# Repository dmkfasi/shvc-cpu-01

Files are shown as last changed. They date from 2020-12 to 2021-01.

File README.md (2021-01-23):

# SHVC-CPU-01

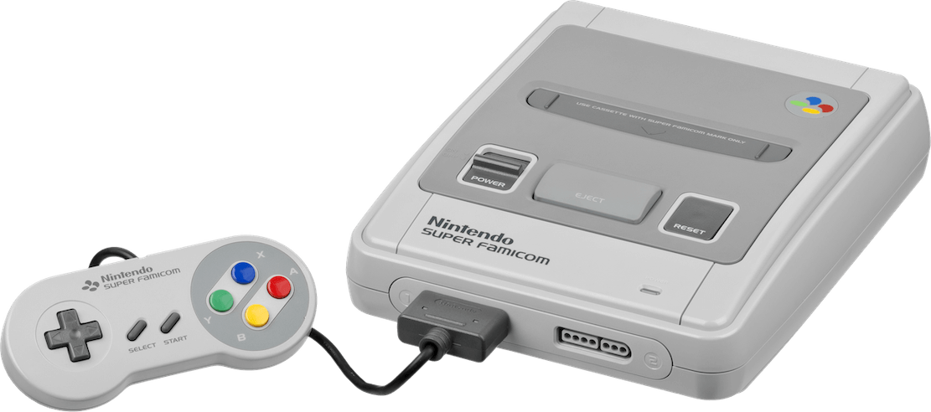
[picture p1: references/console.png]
Super Family Computer


This is a set of electronic schematics to preserve and recreate Super Family Computer also known as Super NES. Based on PDF files created by *Jonathon W. Donaldson* and *arzi84*.

Designed using [KiCAD EDA](https://kicad.org/).

### The primary goal of this project is to verify publicly available schematics for SNS-CPU-GPM-01 (and other revisions) by implementing these in hardware;

The secondary goals of this project are as follows:
1. Recreate the PCB using mixture of original and modern components to fit smaller size case, possibly for portable variant;
1. Get rid of unused components (such as RF modulator, extension ports, etc) or replace them with custom sub-boards or CPLD/FPGA components;
1. Fiddle around with analogue RGB output from S-PPU2 and sniff data bus for possible digital to digital (or digital to VGA) video output;
1. Design a breakout board for video subsystem (S-PPU1, S-PPU2, SRAM) for purpose of BSNES authors to connect such board to a PC and figure out more details for more accurate emulation:
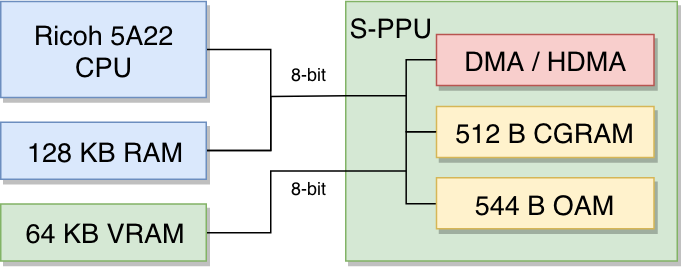
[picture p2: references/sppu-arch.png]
S-PPU architecture
 (drawings by Rodrigo Copetti)

Present limitations:
* ~~S-WRAM chip package is unknown, seems like a custom one, need to measure actual chip and footprint~~ ~~Done, but with impresice tool~~ Verified with digital calipers;
* ~~F411 CIC chip footprint needs verification~~ ~~Done, verified but with imprecise tool~~ Confirmed, see notes below;
* ~~S-SMP QFP-64 14x20mm needs custom designed footprint~~ ~~Done, needs verification against real chip~~ Confirmed QFP-64 14x20mm;
* My reference board is SNS-CPU-RGB-01;

---
Notes and references:

* S-CPU, S-PPU1, S-PPU2 and S-DSP seem to be PQFP-100 14x20mm
* SRAM, PSRAM are standard SOP-28, footprint redesigned
* F411 CIC seems to be SSOP-18 6.0x7.6mm, custom footprint designed
* S-SMP assigned PQFP-64 1.0mm pitch footprint
* S-WRAM assigned SOP-64 0.8mm pitch footprint, 26.6x11.0mm body

* Pin pitch = 2.5mm (not 2.54mm)
* PCB thickness = 1.2mm
* SNS-CPU-RGB-01 PCB thickness = 1.6mm

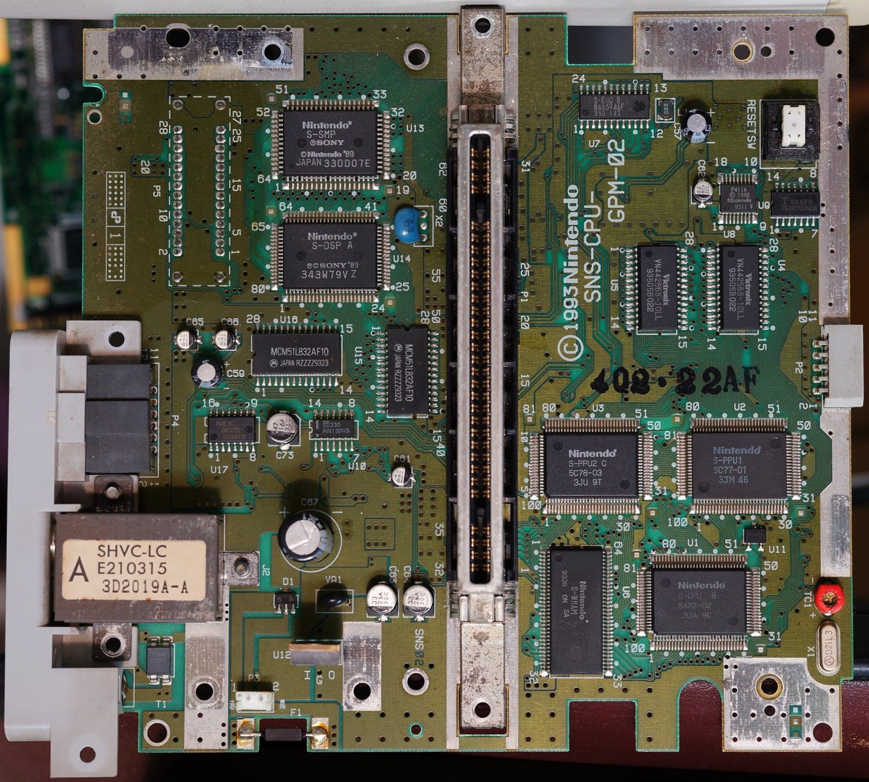
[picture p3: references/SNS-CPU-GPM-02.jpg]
PCB


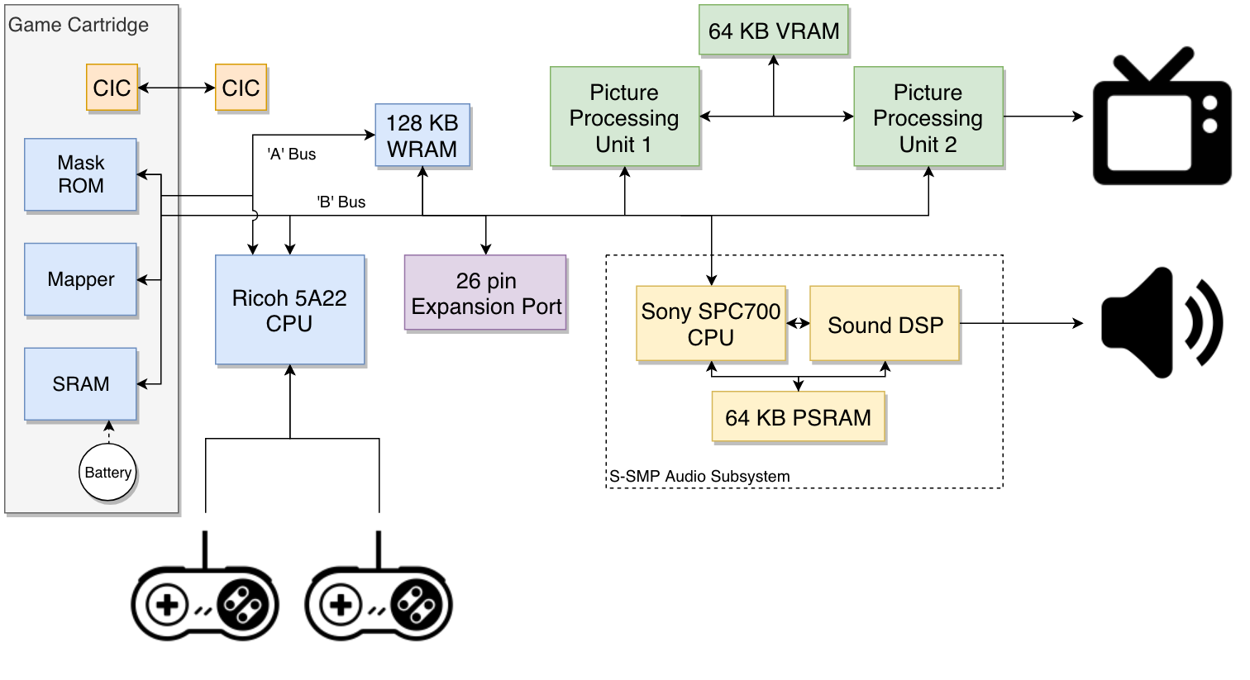
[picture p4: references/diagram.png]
Block diagram
 (drawings by Rodrigo Copetti)

---

# Work in progress
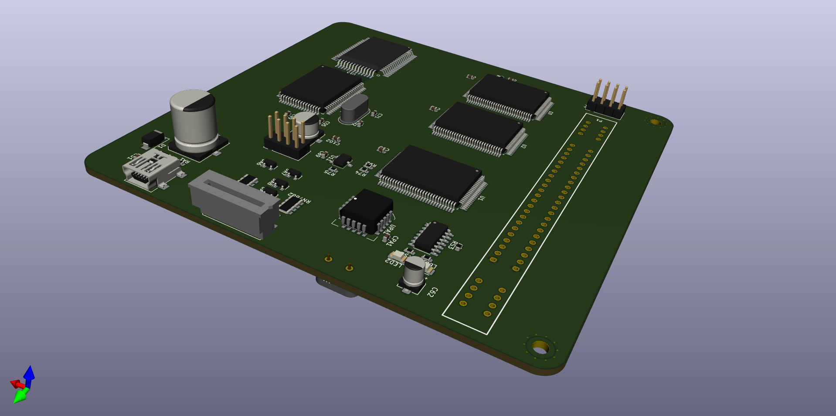
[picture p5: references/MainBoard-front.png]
Front face

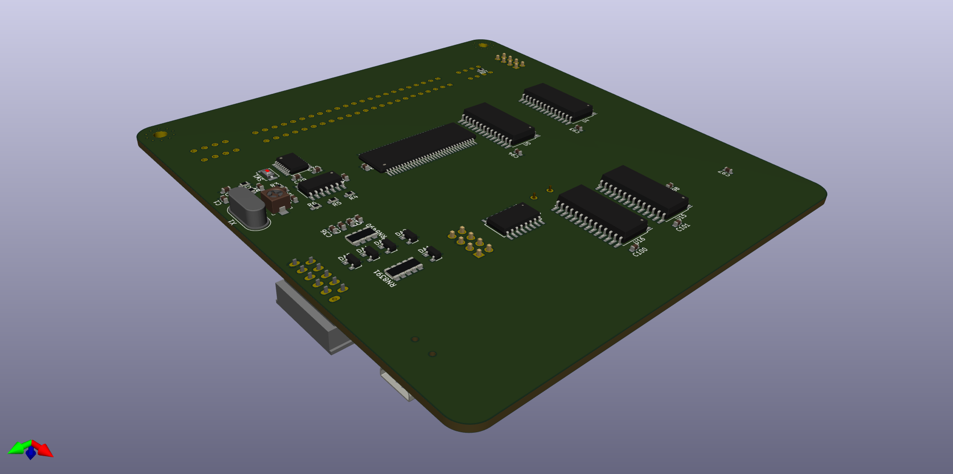
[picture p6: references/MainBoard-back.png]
Back face


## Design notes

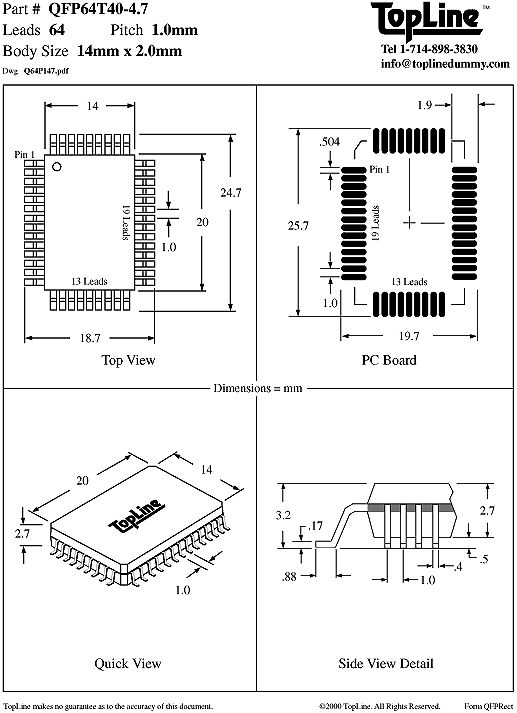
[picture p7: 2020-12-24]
references/QFP64T40-4.7.gif

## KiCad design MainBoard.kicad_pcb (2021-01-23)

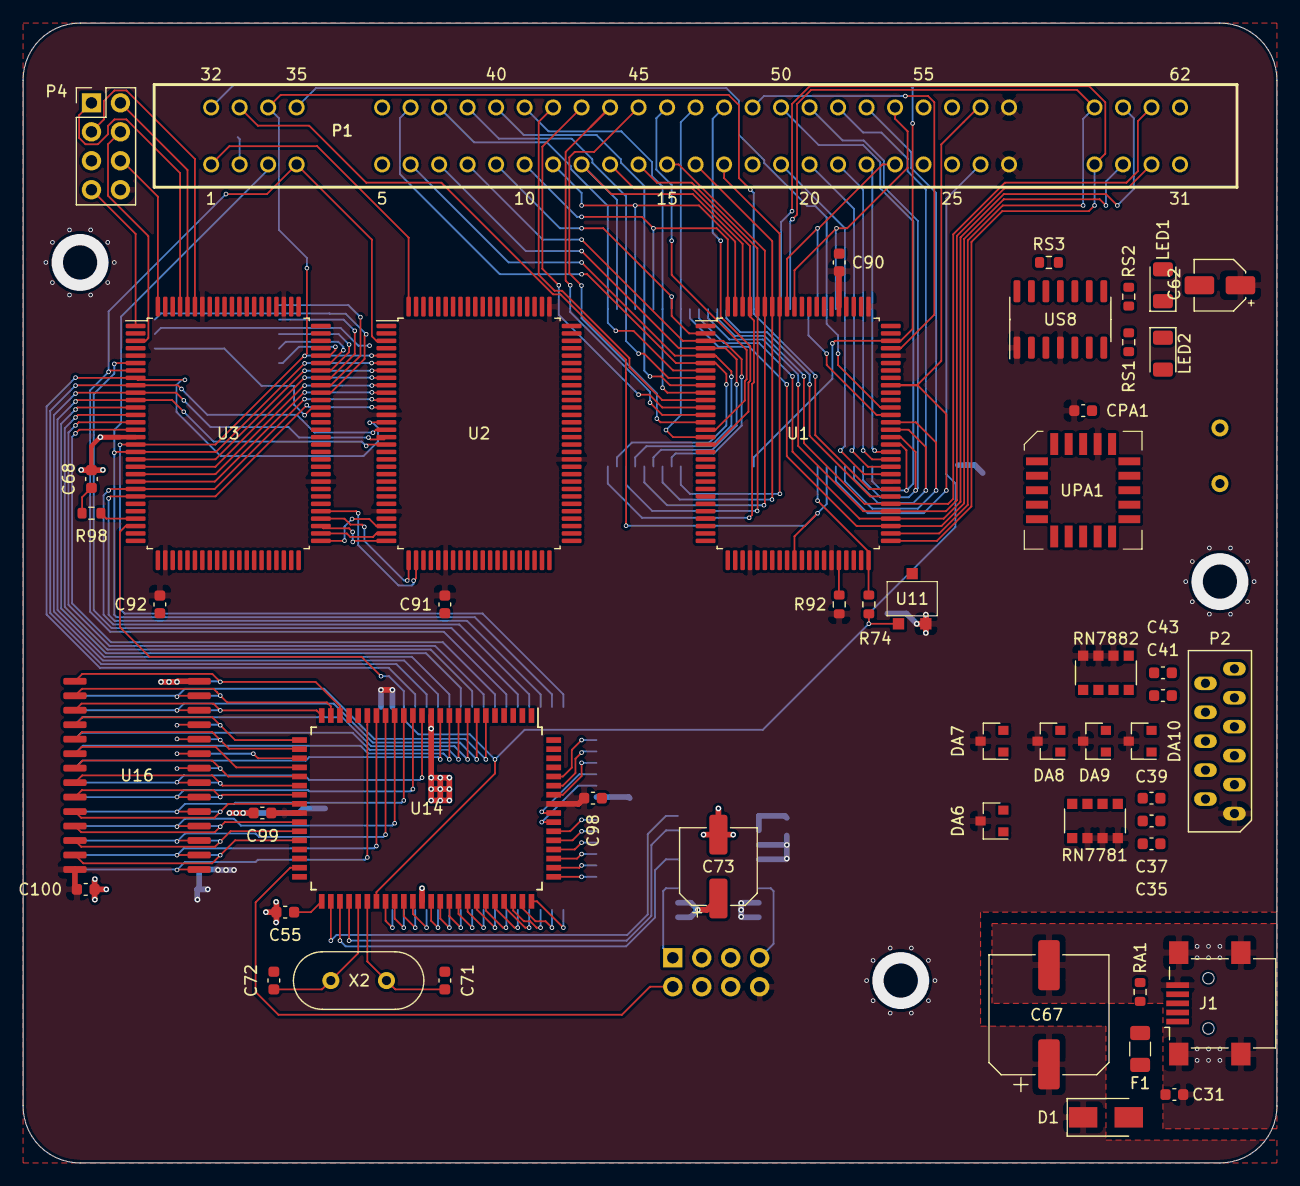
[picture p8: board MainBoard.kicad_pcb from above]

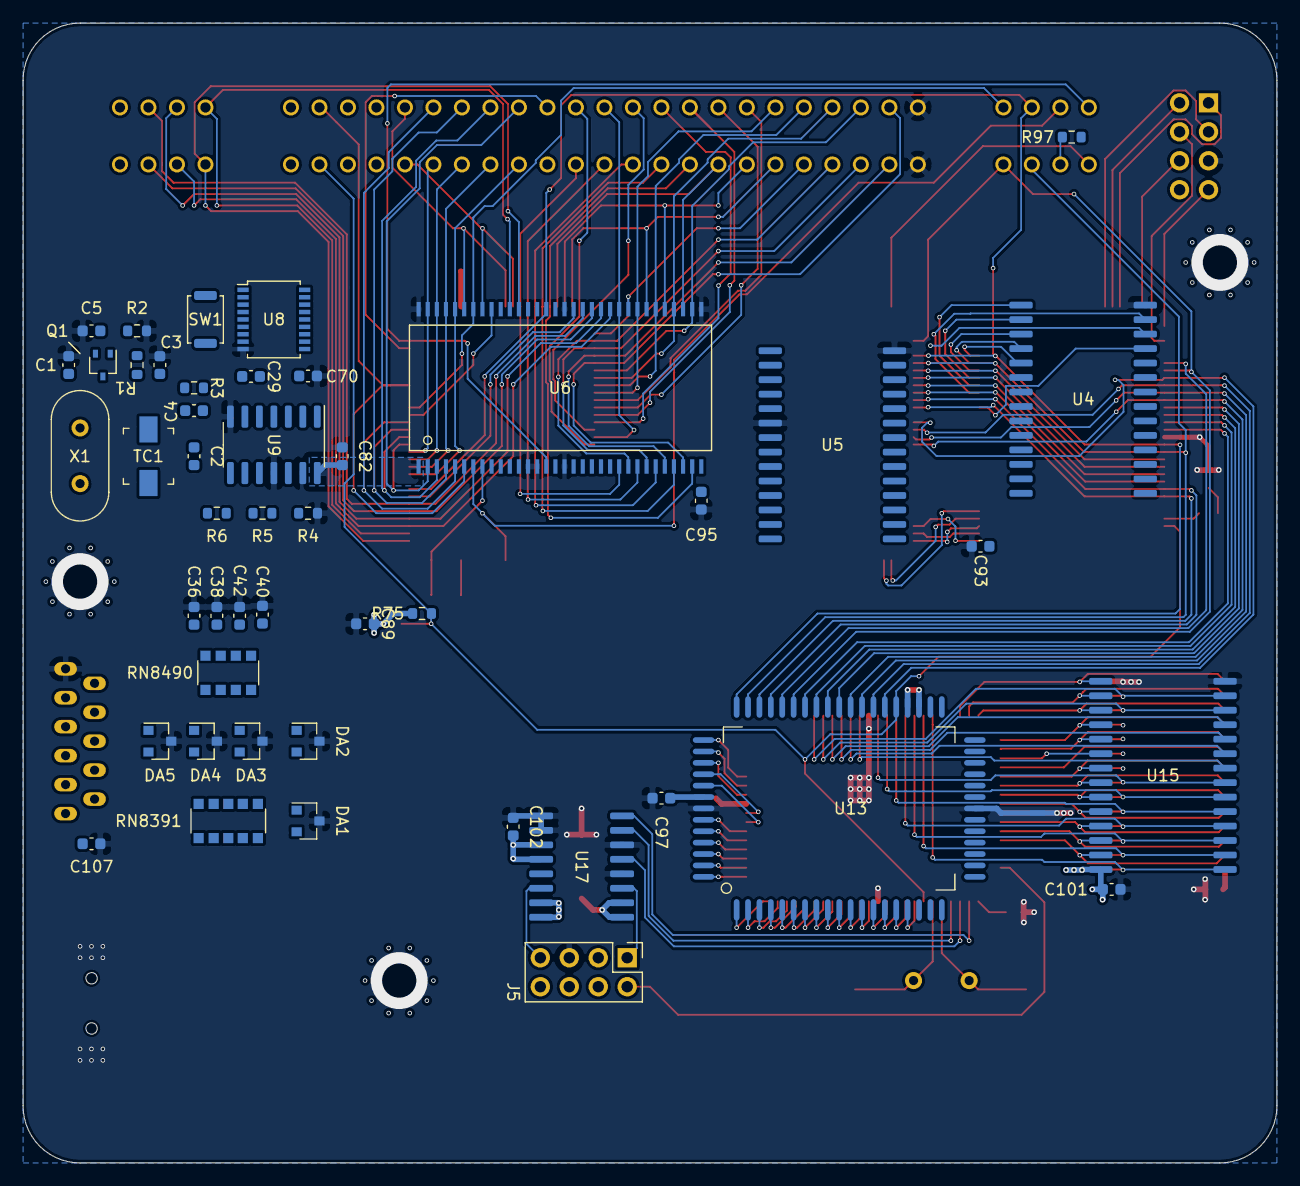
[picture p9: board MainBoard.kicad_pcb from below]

Board: 4 copper layers, 110.0 x 100.0 mm, 98 parts (47 on the bottom side), 236 nets.

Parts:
C1: 47pF; C_0603_1608Metric
C2: 15pF; C_0603_1608Metric
C3: 10pF; C_0603_1608Metric
C4: 100pF; C_0603_1608Metric
C5, C107: 0.01uF; C_0603_1608Metric
C29, C82, C90, C91, C92, C93, C95, C97, C98, C99, C100, C101, C102: 0.1uF; C_0603_1608Metric
C31: 0.01uF 50V; C_0603_1608Metric
C35, C36, C37, C38, C39, C40, C41, C42, C43: 330pF; C_0603_1608Metric
C55: (0); C_0603_1608Metric
C62: 2.2uF; CP_Elec_4x5.4
C67: 1000uF 25V; CP_Elec_10x12.6
C68: 56pF; C_0603_1608Metric
C70: 82pF; C_0603_1608Metric
C71, C72: 3pF; C_0603_1608Metric
C73: 47uF (10V); CP_Elec_6.3x5.4
C89: 100nF; C_0603_1608Metric
CPA1: 100nF; C_0603_1608Metric
D1: PB1100; D_SMA
DA1, DA2, DA3, DA4, DA5: BAT54A; SOT-23
DA6, DA7, DA8, DA9, DA10: BAT54C; SOT-23
F1: Polyfuse; Fuse_1206_3216Metric
J1: USB B Mini; USB_Mini-B_Lumberg_2486_01_Horizontal
J5: Audio Out Port; PinHeader_2x04_P2.54mm_Vertical
LED1: GREEN; LED_1206_3216Metric
LED2: RED; LED_1206_3216Metric
P1: CARTRIDGE_SLOT; SNES_RETRODE_SLOT
P2: FRONT_PANEL_CONNECTOR; SNES_JOYPAD_PORT_ZIP-11
P4: Multi AV Out; PinHeader_2x04_P2.54mm_Vertical
Q1: 2SC4699; SOT-323_SC-70
R1: 56K; R_0603_1608Metric
R2, R4: 210; R_0603_1608Metric
R3: 1.2K; R_0603_1608Metric
R5: 39; R_0603_1608Metric
R6, R75: 100K; R_0603_1608Metric
R74: 1K; R_0603_1608Metric
R92, R97: 10K; R_0603_1608Metric
R98: 100; R_0603_1608Metric
RA1: 100; R_0603_1608Metric
RN7781, RN7882: 10K; R_Array_Convex_4x1206
RN8391: 100; R_Array_Convex_5x1206
RN8490: 100; R_Array_Convex_4x1206
RS1, RS2: 180; R_0603_1608Metric
RS3: 10K; R_0603_1608Metric
SW1: RESET; SW_Push_SPST_NO_Alps_SKRK
TC1: 20pF; C_Trimmer_Murata_TZB4-A
U1: S-CPU; PQFP-100_14x20mm_P0.65mm
U2: S-PPU1; PQFP-100_14x20mm_P0.65mm
U3: S-PPU2; PQFP-100_14x20mm_P0.65mm
U4, U5: SRAM; SOP-28-330mil_P1.27mm
U6: S-WRAM; SOP-64_10.9x26.5mm_P0.8mm
U8: CIC; SSOP-18_4.4x6.5mm_P0.65mm
U9: HCU04; SOIC-14_3.9x8.7mm_P1.27mm
U11: PST529D; MMP-3A
U13: S-SMP; PQFP-64_14x20mm_P1.0mm
U14: S-DSP; PQFP-80_14x20mm_P0.8mm
U15, U16: PSRAM; SOP-28-330mil_P1.27mm
U17: UPD6376; SOP-16-300mil_P1.27mm
UPA1: 16V8; PLCC-20
US8: SuperCIC; SOIC-14_3.9x8.7mm_P1.27mm
X1: 21.47727 MHz; Crystal_HC49-4H_Vertical
X2: 24.576MHz; Crystal_HC49-4H_Vertical

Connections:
/3.58M: P4.4, U3.3
/4016.D0: DA3.2, DA8.1, RN7781.3, RN8391.8, U1.32
/4016.D1: DA3.1, DA8.2, RN7882.1, RN8490.7, U1.33
/4017.D0: DA4.2, DA9.1, RN7781.2, RN8391.9, U1.27
/4017.D1: DA4.1, DA9.2, RN7882.2, RN8490.6, U1.28
/$214F_PATCH: UPA1.13, US8.3
/AUDIO_LOUT: J5.1, U17.11
/AUDIO_ROUT: J5.7, U17.6
/CA0: P1.17, U1.93, U6.23
/CA1: P1.16, U1.94, U6.25
/CA2: P1.15, U1.95, U6.27
/CA3: P1.14, U1.96, U6.29
/CA4: P1.13, U1.97, U6.31
/CA5: P1.12, U1.98, U6.35
/CA6: P1.11, U1.99, U6.37
/CA7: P1.10, U1.100, U6.39
/CA8: P1.9, U1.2, U6.41
/CA9: P1.8, U1.3, U6.24
/CA10: P1.7, U1.4, U6.26
/CA11: P1.6, U1.5, U6.28
/CA12: P1.37, U1.6, U6.30
/CA13: P1.38, U1.7, U6.34
/CA14: P1.39, U1.8, U6.36
/CA15: P1.40, U1.9, U6.38
/CA16: P1.41, U1.10, U6.40
/CA17: P1.42, U1.11
/CA18: P1.43, U1.12
/CA19: P1.44, U1.13
/CA20: P1.45, U1.14
/CA21: P1.46, U1.15
/CA22: P1.47, U1.16, U6.42
/CA23: P1.48, U1.17
/CART_SOUND-L: J5.3, P1.31
/CART_SOUND-R: J5.6, P1.62
/CHR0: U2.85, U3.46
/CHR1: U2.84, U3.47
/CHR2: U2.83, U3.48
/CHR3: U2.82, U3.49
/CIC0: P1.24, U8.2, US8.9
/CIC1: P1.55, U8.1, US8.10
/CIC2: P1.25, U8.11, US8.8
/CIC3: C70.1, P1.56, U9.2
/CIC_CL1: U8.7, U9.4, US8.2
/CIC_RESET: C29.2, RS3.2, SW1.1, U8.8, US8.13
/COLOR0: U2.90, U3.41
/COLOR1: U2.89, U3.42
/COLOR2: U2.88, U3.43
/D0: P1.19, U1.60, U2.21, U3.15, U6.60, U13.45
/D1: P1.20, U1.61, U2.20, U3.14, U6.61, U13.44
/D2: P1.21, U1.62, U2.19, U3.13, U6.62, U13.43
/D3: P1.22, U1.63, U2.18, U3.12, U6.63, U13.42
/D4: P1.50, U1.64, U2.17, U3.11, U6.2, U13.41, UPA1.16, UPA1.17, UPA1.18, UPA1.19
/D5: P1.51, U1.65, U2.16, U3.10, U6.3, U13.40
/D6: P1.52, U1.66, U2.15, U3.9, U6.4, U13.39
/D7: P1.53, U1.67, U2.14, U3.8, U6.5, U13.38
/FIELD: U2.95, U3.36
/HBLANK: U1.43, U3.25
/JPCLK1: DA2.2, DA7.1, RN8391.7, U1.35
/JPCLK2: DA2.1, DA7.2, RN8490.8, U1.36
/JPIO6: DA5.2, DA10.1, RN7781.1, RN8391.10, U1.25
/JPIO7: DA5.1, DA10.2, RN7882.3, RN8490.5, U1.26, U3.29
/JPSTR: DA1.1, DA6.2, RN8391.6, U1.37
/MA0: U14.9, U15.10, U16.10
/MA1: U14.10, U15.9, U16.9
/MA2: U14.11, U15.8, U16.8
/MA3: U14.13, U15.7, U16.7
/MA4: U14.14, U15.6, U16.6
/MA5: U14.15, U15.5, U16.5
/MA6: U14.16, U15.4, U16.4
/MA7: U14.17, U15.3, U16.3
/MA8: U14.34, U15.25, U16.25
/MA9: U14.32, U15.24, U16.24
/MA10: U14.29, U15.21, U16.21
/MA11: U14.31, U15.23, U16.23
/MA12: U14.18, U15.2, U16.2
/MA13: U14.35, U15.26, U16.26
/MA14: U14.19, U15.1, U16.1
/MD0: U14.8, U15.11, U16.11
/MD1: U14.7, U15.12, U16.12
/MD2: U14.6, U15.13, U16.13
/MD3: U14.22, U15.15, U16.15
/MD4: U14.23, U15.16, U16.16
/MD5: U14.24, U15.17, U16.17
/MD6: U14.25, U15.18, U16.18
/MD7: U14.26, U15.19, U16.19
/PA0: P1.28, U1.51, U2.12, U3.24, U6.53, U13.49, UPA1.1
/PA1: P1.59, U1.52, U2.11, U3.23, U6.54, U13.48, UPA1.5
/PA2: P1.29, U1.53, U2.10, U3.22, U6.43, UPA1.2
/PA3: P1.60, U1.54, U2.9, U3.21, U6.44, UPA1.6
/PA4: P1.30, U1.55, U2.8, U3.20, U6.45, UPA1.3
/PA5: P1.61, U1.56, U2.7, U3.19, U6.46, UPA1.7
/PA6: P1.3, U1.57, U2.6, U3.18, U6.47, U13.50, UPA1.4
/PA7: P1.34, U1.58, U2.5, U3.17, U6.50, U13.51, UPA1.8
/PRIO0: U2.87, U3.44
/PRIO1: U2.86, U3.45
/Post_Amplifier: DA1.2, DA6.1
/REFRESH: P1.33, U1.40, U6.7
/SCLK: C55.1, U9.1, U9.3, U14.41
/SYSCK: P1.57, U1.72, U6.6
/VA14: U2.47, U4.1, U5.1
/VAA0: U2.76, U5.10
/VAA1: U2.75, U5.9
/VAA2: U2.74, U5.8
/VAA3: U2.73, U5.7
/VAA4: U2.72, U5.6
/VAA5: U2.71, U5.5
/VAA6: U2.70, U5.4
/VAA7: U2.69, U5.3
/VAA8: U2.68, U5.25
/VAA9: U2.67, U5.24
/VAA10: U2.66, U5.21
/VAA11: U2.65, U5.23
/VAA12: U2.64, U5.2
/VAA13: U2.63, U5.26
/VAB0: U2.61, U4.10
/VAB1: U2.60, U4.9
/VAB2: U2.59, U4.8
/VAB3: U2.58, U4.7
/VAB4: U2.57, U4.6
/VAB5: U2.56, U4.5
/VAB6: U2.55, U4.4
/VAB7: U2.54, U4.3
/VAB8: U2.53, U4.25
/VAB9: U2.52, U4.24
/VAB10: U2.51, U4.21
/VAB11: U2.50, U4.23
/VAB12: U2.49, U4.2
/VAB13: U2.48, U4.26
/VBLANK: U1.44, U3.26
/VDA0: U2.37, U3.60, U5.11
/VDA1: U2.38, U3.61, U5.12
/VDA2: U2.39, U3.62, U5.13
/VDA3: U2.40, U3.63, U5.15
/VDA4: U2.41, U3.64, U5.16
/VDA5: U2.42, U3.65, U5.17
/VDA6: U2.43, U3.66, U5.18
/VDA7: U2.44, U3.67, U5.19
/VDB0: U2.28, U3.51, U3.69, U4.11
/VDB1: U2.29, U3.52, U3.70, U4.12
/VDB2: U2.30, U3.53, U3.71, U4.13
/VDB3: U2.31, U3.54, U3.72, U4.15
/VDB4: U2.32, U3.55, U3.73, U4.16
/VDB5: U2.33, U3.56, U3.74, U4.17
/VDB6: U2.34, U3.57, U3.75, U4.18
/VDB7: U2.35, U3.58, U3.76, U4.19
/VIDEO_B: P4.3, U3.95
/VIDEO_G: P4.2, U3.96
/VIDEO_R: P4.1, U3.97
/XIN: P1.1, R4.2, R5.1, U1.48, U2.100, U3.31
/~5MIN: U2.93, U2.94, U2.97, U3.37, U3.38, U3.50
/~CE0: U14.28, U16.20
/~CE1: U14.27, U15.20
/~CPURD: P1.23, U1.92, U6.57
/~CPUWR: P1.54, U1.91, U6.59
/~HCLD: U2.92, U3.39
/~IRQ: P1.18, R92.2, U1.46
/~MUTE: J5.2, U14.39
/~OE: U14.30, U15.22, U16.22
/~PARD: P1.4, U1.68, U2.3, U3.7, U6.56, U13.46, UPA1.9
/~PAWR: P1.35, U1.69, U2.4, U3.6, U6.58, U13.47
/~RAMSEL: P1.32, U1.78, U6.15
/~RESET: U3.34, U8.10, US8.11
/~RESOUT0: U2.98, U3.33
/~RESOUT1: P1.26, R74.1, R74.2, R75.1, U1.50, U3.28, U6.8, U11.2, U13.37, U14.47
/~ROMSEL: P1.49, U1.77
/~VAWR: U2.78, U5.27
/~VBWR: U2.79, U4.27
/~VCLD: U2.91, U3.40
/~VIDEO_BURST: P4.6, U3.100
/~VIDEO_CSYNC: P4.7, U3.1
/~VRD: U2.80, U4.22, U5.22
/~WE: U14.36, U15.27, U16.27
GND: C1.2, C3.2, C5.2, C31.1, C35.2, C36.2, C37.2, C38.2, C39.2, C40.1, C41.2, C42.2, C43.2, C55.2, C67.2, C68.2, C70.2, C71.1, C72.1, C73.2, C82.2, C89.2, C90.1, C91.1, C92.1, C93.1, C95.1, C97.2, C98.1, C99.2, C100.1, C101.1, C102.1, C107.2, CPA1.2, DA1.3, DA2.3, DA3.3, DA4.3, DA5.3, J1.5, J1.6, J5.5, LED1.1, LED2.1, P1.5, P1.36, P2.11, P4.5, R2.1, R4.1, RS3.1, U1.18, U1.29, U1.30, U1.31, U1.41, U1.42, U1.47, U1.49, U1.73, U1.74, U1.75, U1.79, U1.90, U2.1, U2.2, U2.22, U2.23, U2.24, U2.25, U2.27, U2.45, U2.77, U2.96, U2.99, U3.16, U3.30, U3.35, U3.68, U3.90, U3.91, U3.92, U3.93, U3.98, U3.99, U4.14, U4.20, U5.14, U5.20, U6.13, U6.14, U6.17, U6.33, U6.48, U6.64, U8.9, U9.7, U9.11, U9.13, U11.3, U13.26, U13.58, U14.12, U14.37, U14.38, U14.52, U15.14, U16.14, U17.1, U17.2, U17.12, U17.14, UPA1.10, US8.7, US8.12, US8.14
unnamed: C1.1, X1.2
unnamed: C2.1, TC1.1, X1.1
unnamed: C2.2, C3.1, C4.2, Q1.3, R1.2, R3.1, TC1.2
unnamed: C4.1, R6.2, U9.9
unnamed: C5.1, Q1.2, R2.2
unnamed: C31.2, D1.2, F1.2
unnamed: C35.1, P2.2, RN8391.1
unnamed: C36.1, P2.3, RN8490.4
unnamed: C37.1, P2.4, RN8391.2
unnamed: C38.1, P2.5, RN8490.3
unnamed: C39.1, P2.6, RN8391.3
unnamed: C40.2, P2.7, RN8490.2
unnamed: C41.1, P2.8, RN8391.4
unnamed: C42.1, P2.9, RN8490.1
unnamed: C43.1, P2.10, RN8391.5
unnamed: C62.2, U8.3
unnamed: C68.1, R98.2
unnamed: C71.2, U14.46, X2.2
unnamed: C72.2, U14.45, X2.1
unnamed: C73.1, U17.9, U17.10
unnamed: F1.1, J1.1
unnamed: J1.2, RA1.1
unnamed: J1.3, RA1.2
unnamed: LED1.2, RS2.1
unnamed: LED2.2, RS1.2
unnamed: P1.2, R97.2
unnamed: Q1.1, R1.1
unnamed: R5.2, U9.6
unnamed: R6.1, U9.5, U9.8
unnamed: R98.1, U3.27
unnamed: RS1.1, US8.6
unnamed: RS2.2, US8.5
unnamed: U13.1, U14.64
unnamed: U13.2, U14.63
unnamed: U13.3, U14.62
unnamed: U13.4, U14.61
unnamed: U13.5, U14.60
unnamed: U13.6, U14.59
unnamed: U13.7, U14.58
unnamed: U13.8, U14.57
unnamed: U13.9, U14.56
unnamed: U13.10, U14.55
unnamed: U13.11, U14.54
unnamed: U13.12, U14.53
unnamed: U13.13, U14.51
unnamed: U13.14, U14.50
unnamed: U13.15, U14.49
unnamed: U13.16, U14.48
unnamed: U13.52, U14.76
unnamed: U13.53, U14.75
unnamed: U13.54, U14.74
unnamed: U13.55, U14.72
unnamed: U13.56, U14.71
unnamed: U13.59, U14.70
unnamed: U13.60, U14.69
unnamed: U13.61, U14.68
unnamed: U13.62, U14.67
unnamed: U13.63, U14.66
unnamed: U13.64, U14.65
unnamed: U14.42, U17.16
unnamed: U14.43, U17.13
unnamed: U14.44, U17.15
VCC: C29.1, C62.1, C67.1, C82.1, C89.1, C90.2, C91.2, C92.2, C93.2, C95.2, C97.1, C98.2, C99.1, C100.2, C101.2, C102.2, C107.1, CPA1.1, D1.1, DA6.3, DA7.3, DA8.3, DA9.3, DA10.3, J5.8, P1.27, P1.58, P2.1, P4.8, R3.2, R75.2, R92.1, R97.1, RN7781.6, RN7781.7, RN7781.8, RN7882.6, RN7882.7, RN7882.8, SW1.2, U1.1, U1.34, U1.45, U1.59, U1.76, U1.81, U1.85, U2.13, U2.26, U2.36, U2.62, U2.81, U3.5, U3.32, U3.59, U3.83, U3.94, U4.28, U5.28, U6.1, U6.10, U6.11, U6.12, U6.16, U6.32, U6.49, U6.51, U6.52, U8.4, U8.18, U9.14, U11.1, U13.35, U13.36, U13.57, U14.33, U14.73, U15.28, U16.28, U17.3, U17.4, U17.7, U17.8, UPA1.20, US8.1, US8.4

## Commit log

2020-12-21 Joypad front panel connector added
2020-12-22 Cartridge Slot started
2020-12-22 Cartridge Slot left side completed
2020-12-22 Cartridge Slot completed
2020-12-24 S-CPU footprint and datasheet link added
2020-12-24 Footprints added
2020-12-24 Reference material
2020-12-24 Local footprint cache
2020-12-25 Initial placement
    [MainBoard.sch]
2020-12-25 Cart slot gerber layer
    [top_v3.GBL, top_v3.GBO, top_v3.GBS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]
2020-12-25 Chips placed
    [MainBoard.sch]
2020-12-26 Primary components placed and annotated
    [MainBoard.sch]
2020-12-26 Text alignments and annotations
    [MainBoard.sch]
2020-12-26 Current annotation file
2020-12-26 Fix to match library components
    [MainBoard.sch]
2020-12-26 Cartridge Slot footprint added
2020-12-26 Cart slot footprint assigned
2020-12-26 Local footprint appointed
2020-12-26 Symbols aligned
    [MainBoard.sch]
2020-12-26 Cart slot footprint added
2020-12-26 Replaced with local copy footprints
    [MainBoard.sch]
2020-12-26 Preliminarily S-WRAM footprint
2020-12-27 JPIO port wired
    [MainBoard.sch]
2020-12-27 S-CPU started
    [MainBoard.sch]
2020-12-27 JPIO connector corrected to fit schematics better
2020-12-27 S-PPU1 + VRAM1
    [MainBoard.sch]
2020-12-27 VRAM1 + VRAM2 + S-PPU1
    [MainBoard.sch]
2020-12-27 VRAM rd/wr bus finished
    [MainBoard.sch]
2020-12-28 Cart slot and PPU somewhat wired up
    [MainBoard.sch]
2020-12-28 S-PPU2 wiring started
    [MainBoard.sch]
2020-12-28 CIC completed, Xtal started
    [MainBoard.sch]
2020-12-28 Joypad port footprint ZIP-11
2020-12-28 U11 added
    [MainBoard.sch]
2020-12-28 S-SMP CPU footprint
2020-12-29 For U11 Power Supervisor
2020-12-29 XIN added, PPU2 mostly done, S-SMP and S-DSP started
    [MainBoard.sch]
2020-12-30 Passive pin fixes for multiple components
2020-12-30 Mostly complete, no ERC errors/warnings
    [MainBoard.sch]
2021-01-02 SuperCIC added, D4 patch added
    [MainBoard.sch]
2021-01-02 Capacitor footprints added
    [MainBoard.sch]
2021-01-02 Most footprints added
    [MainBoard.sch]
2021-01-02 Resistor footprints added
    [MainBoard.sch]
2021-01-02 Missing footprints added
    [MainBoard.sch]
2021-01-02 Current netlist
2021-01-02 Pin numbers assigned
2021-01-02 Notes errata, 213f PLD version added
    [MainBoard.sch]
2021-01-02 Missing footprint added, Notes errata
    [MainBoard.sch]
2021-01-02 Local copy for 3D shapes
    [039532105.stp]
2021-01-02 Fixed multiple footprints for UP3
    [MainBoard.sch]
2021-01-02 WIP DRAFT
    [MainBoard.kicad_pcb]
2021-01-02 Moved to proper name packages3d
    [039532105.stp]
2021-01-02 Reassigned footprints and 3D models
    [MainBoard.kicad_pcb]
2021-01-02 Fixed footprints for Reset Button, X2 and UPA1
    [MainBoard.sch]
2021-01-03 Correct footprint for SRAM
2021-01-03 Current settings
2021-01-03 Fixed footprints for SRAM chips
2021-01-03 S-CPU and S-WRAM mostly wired
    [MainBoard.kicad_pcb]
2021-01-04 Fixed footprint size for C62, rewired RN7882 for better fit on PCB
    [MainBoard.sch]
2021-01-04 Properly laid out XIN and Gamepad portions, the rest is WIP
    [MainBoard.kicad_pcb]
2021-01-11 Replaced footprint with 2.54mm pitch for easier routing and debugging
    [MainBoard.sch]
2021-01-11 Component layout is done
    [MainBoard.kicad_pcb]
2021-01-12 Current board layout visualization
2021-01-12 Board current 3D view added
2021-01-13 Correct footprint for SRAM/PSRAM
2021-01-13 Footprint reference for SOP-28 330mil
2021-01-13 Fixed wrong SRAM/PSRAM footprints
    [MainBoard.kicad_pcb]
2021-01-13 Fixed U17 footprint
    [MainBoard.sch]
2021-01-13 Footprints reassigned, playing around PSRAM
    [MainBoard.kicad_pcb]
2021-01-15 Resized, refilled DC in section, compacted
    [MainBoard.kicad_pcb]
2021-01-17 Front/Back Silk Screen laid out
    [MainBoard.kicad_pcb]
2021-01-18 Sound section wiring completed
    [MainBoard.kicad_pcb]
2021-01-18 Updated PWR net track with to 0.5mm
2021-01-18 Swapped LAUDIO and MUTE on J5 for better PCB layout
    [MainBoard.sch]
2021-01-18 Sound section connected to the main CPU now
    [MainBoard.kicad_pcb]
2021-01-23 WIP, needs rewiring
    [MainBoard.kicad_pcb]
2021-01-23 Fixed nasty bug with /XIN /RESET interconnection
    [MainBoard.sch]
2021-01-23 Updated and moved to 10.9x26.5mm
